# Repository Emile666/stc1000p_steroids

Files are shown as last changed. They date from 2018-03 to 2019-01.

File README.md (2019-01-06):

STC-1000p on steroids
==========

This is a version of the STC-1000p (STC-1000p-STM8) with new hardware and a new microcontroller, the **STM8S105C6T6**. It is a major upgrade to the stock **STM8S003F3** µC. In the version, you get all the exciting features from
the stc-1000p-stm8 version (including the PID-control with SSR output), PLUS:
- Three additional LEDs placed directly above the 7-segment display. These can be used for all kinds of indications.
- One-wire interface, so you can hook up a **DS18B20** One-Wire temperature-sensor for reliable temperature measurements.
- **I<sup>2</sup>C**-interface for additional connection to other hardware (e.g. a MCP23017 16-bit IO expander to control solenoid ball valves).
- An **UART** interface so that commands can be sent using serial communication.
- A **433 MHz** transmitter interface is added so that temperatures and relay on/off are sent (using the Fine Offset protocol from Matts original fimware).
- Interface for an **nRF24L01+** 2.4 GHz transceiver. Now you can control and communicate wireless with the STC1000p. The nRF24L01+ is known to have a large range (up to 100 metres is reported).

The **STM8S105C6T6** µC has 32 Kbytes of Flash memory, 1024 bytes of EEPROM and 2 Kbytes of RAM. So there's plenty of room for all new functionality. It also has more than sufficient IO pins, since it is a LQFP48 package.

I designed a new frontpanel PCB and backplane PCB that are the exact same sizes as the current PCBs. So it fits the existing housing.

Software Development Environment
-----------
- Cosmic STM8 compiler. A license can be obtained free of charge from Cosmic-software.com. Install this first.
- ST Visual Develop (STVD). This can be obtained free of charge from st.com
- A coloured ST-Link V2 USB adapter (which are very cheap to find on ebay)

In order to program this thing, you can't have a code-size limit of 8 Kbytes, so IAR will not do the job. Fortunately, the Cosmic STM8 development environment (IdeaSTM8) has been made available free-of-charge. Just register and download and you have 
a development environment that nicely supports this device.

Quick start
-----------
Assuming that you have bought (at least) one of those existing stc1000 on ebay/aliexpress, you need to do the following:
- Open the housing of the stc1000. There are a few clips on the side and you should make a cut in the sticker. Bend the clips (carefully) and pull the frontpanel out.
- The frontpanel PCB needs to be deconnected from the backplane. Remove all the solder-joints with the solder wick (or use a desoldering-iron). Place the solder wick over the solder-joints, heat it up with the soldering iron and make sure that the solder wick absorbs all solder.
After having done this, it is possible to remove the frontpanel from the backplane with just a little bit of pulling. Be careful, since you don't want to break anything.
- The 7-segment display is connected to the frontpanel with 12 pins and is going to be re-used. It is an essential part, so de-solder this from the frontpanel PCB. Be careful not to break anything.
- If you wish, you can desolder a few parts from the backplane PCB, such as terminal blocks and relays. I replaced the stock relays with 16 A versions (Omron G5LE-1-E 12VDC).
- Get yourself some PCBs (see below) and do some soldering...

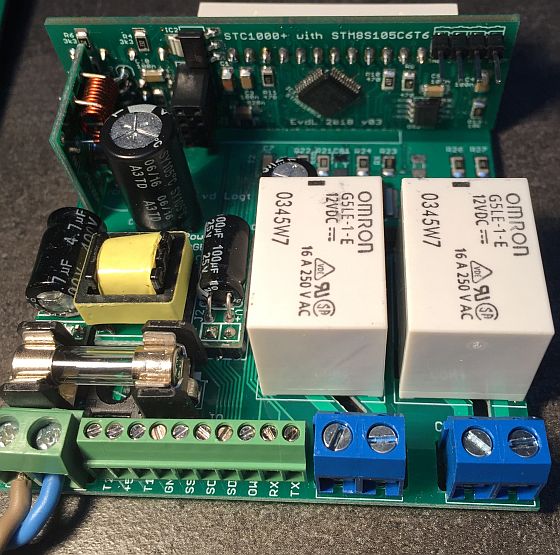
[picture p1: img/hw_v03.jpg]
hw_v03
<br>
*This is how it should look: frontpanel v03 connected to new backplane PCB*

Introduction
--------------
Much of this project is still work in progress, with hardware already pretty stable. The basic software from the stc1000p project runs, but most additional features mentioned above need to be added to the firmware.

I work on this from time to time, so it is not a completely finished project yet.

UART Communication protocol
--------------
If you connect an UART (+3.3V!) to USB device, it is possible to communicate with the stc1000 using commands. Currently the following commands are available:
- **S0**: print the current revision number of the software
- **S1**: Lists the address of all connected I2C devices. It should show at least 0x40, which is the I2C address for the DS2482 I2C to One-Wire device.
- **S2**: Lists all tasks of the scheduler. It should show 4 tasks.
- **S3**: Shows the temperature and status of a connected DS18B20 One-Wire device. It should read ds18b20_read():0 (1 = error) and the actual temperature of the sensor
- **O1** and **O0**: the O1 commands selects the One-wire temperature sensor over the default NTC sensor. The O0 command selects the default NTC sensor again. The selected sensorvalue is displayed on-screen and is used for both temperature and pid-control.

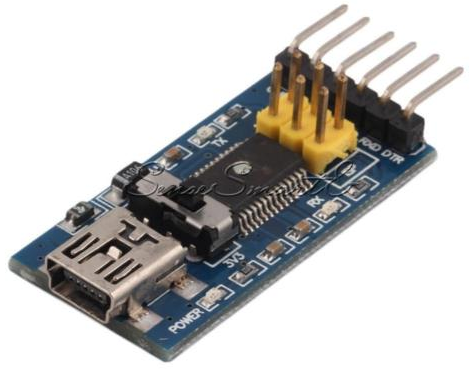
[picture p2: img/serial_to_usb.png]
serial_to_usb
<br>
*Serial (UART) to USB interface*

Frontpanel PCB
----------
Here's version 03 of the new frontpanel PCB.

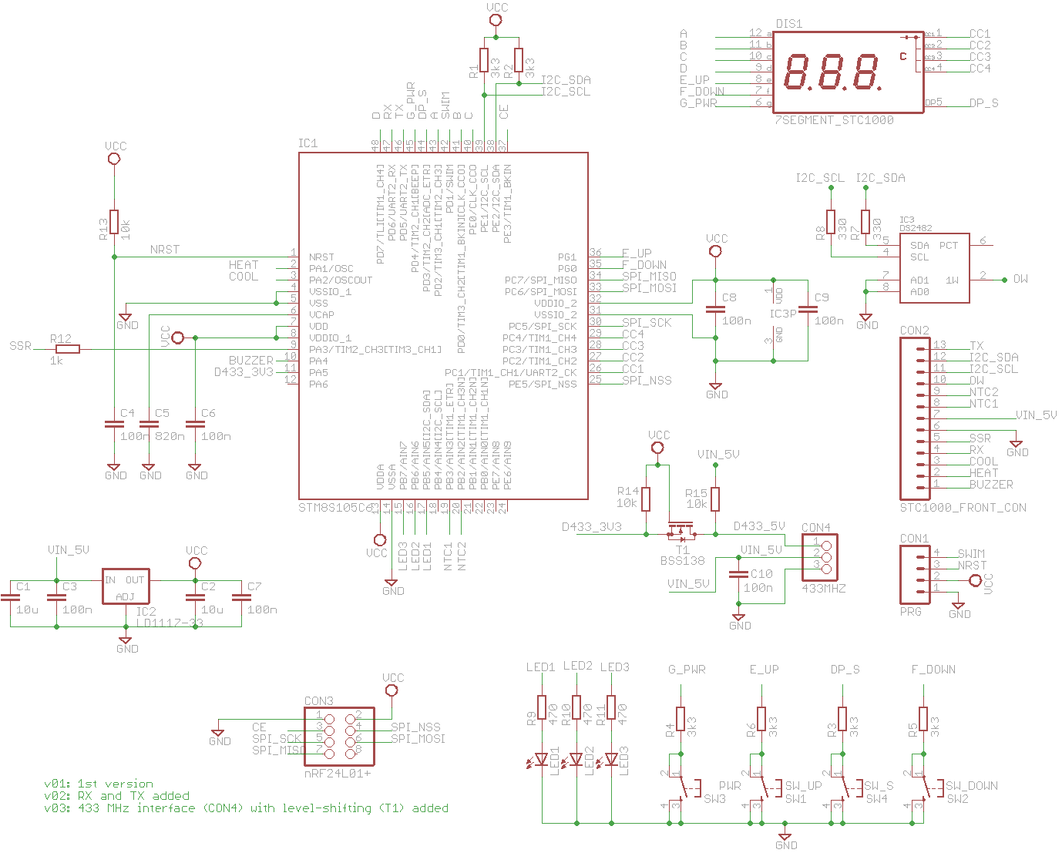
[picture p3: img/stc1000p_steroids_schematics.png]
<br>
*Eagle schematics v03 of the Frontpanel with an STM8S105C6 µC*

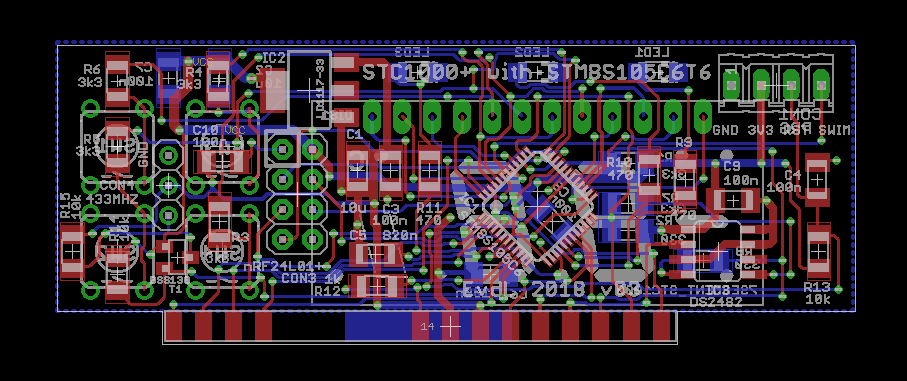
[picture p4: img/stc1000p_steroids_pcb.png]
<br>
*Eagle PCB of the Frontpanel, v03*

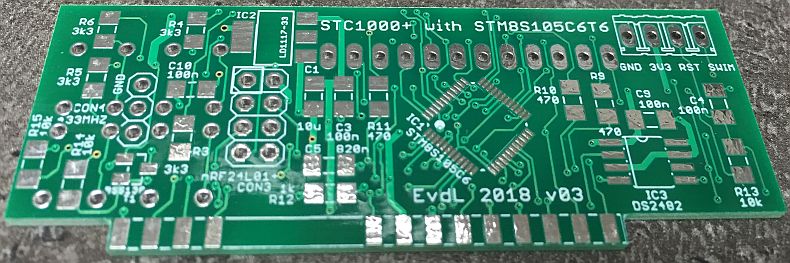
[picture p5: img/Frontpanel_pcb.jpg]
frontpanel
<br>
*PCB as received from the PCB manufacturer (allpcb.com).*

Backplane PCB
----------
Although it is possible to connect the frontpanel PCB directly to an existing backplane, it is much more useful to replace this with a new backplane. Main advantage is that you will have decent access to all new features via connectors at the back.

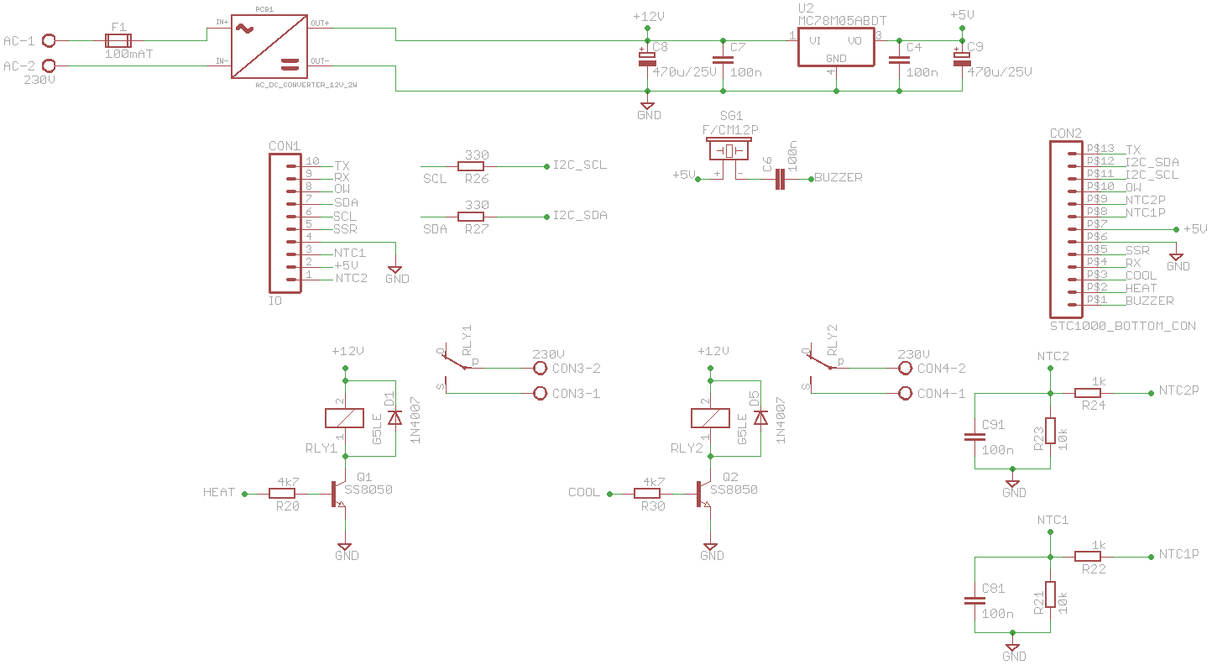
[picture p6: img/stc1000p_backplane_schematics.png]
backplane
<br>
*Eagle schematics of the new backplane*

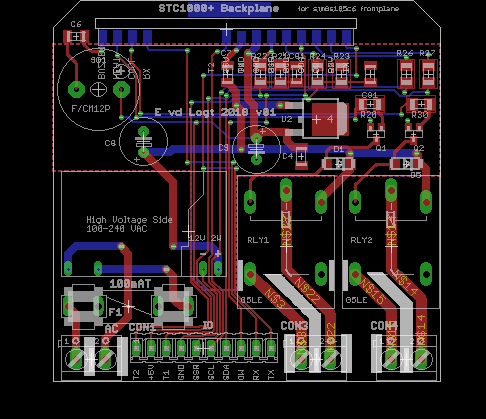
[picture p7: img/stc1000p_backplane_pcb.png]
backplane
<br>
*Eagle PCB of the new backplane*

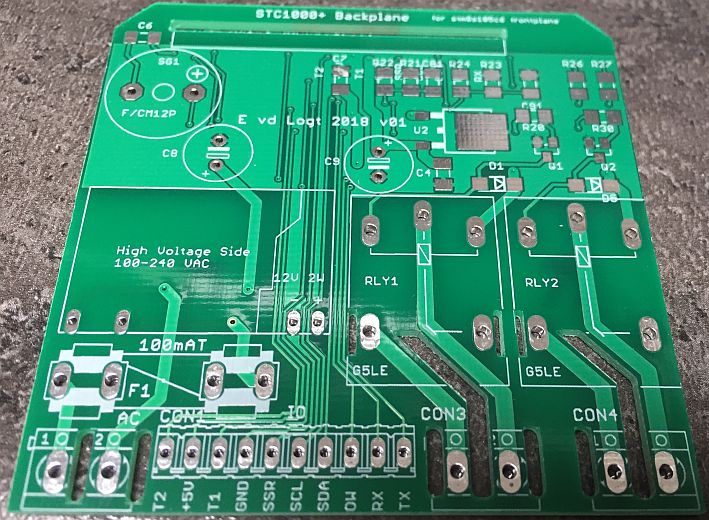
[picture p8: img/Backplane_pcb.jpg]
backplane
<br>
*PCB as received from the PCB manufacturer (allpcb.com).*

There's now a 10 pole terminal-block with the following connections:
- **T2**: connect a 2nd temperature sensor to this pin and the +3.3V pin (same as in Matts' firmware)
- **+5V**: +5V power-supply voltage (same as in original STC1000). **BUG**: this should be 3.3V.
- **T1**: connect a temperature sensor (10 k NTC) to this pin and the +5V pin (same as in original STC1000)
- **GND**: ground (0 V) connection. 
- **SSR**: SSR output. Connect this to the input line of a solid-state relay. This is a PID controlled output.
- **SCL**: Serial clock-line of the I<sup>2</sup>C interface.
- **SDA**: Serial data-line of the I<sup>2</sup>C interface.
- **OW**: One-wire output. Support a DS18B20 temperature sensor for more accurate readings.
- **RX**: Receive-data pin for the serial communication (UART). This is a 3.3 Volt pin, so do not connect higher voltages!
- **TX**: Transmit-data pin for the serial communication (UART). This is a 3.3 Volt pin, so do not connect higher voltages!

Updates
-------

|Date|Release|Description|
|----|---|---|
|2016-12-10|v1.00|First release |
|2018-03-23|v1.10|Frontpanel PCB update + new backplane PCB added|
|2019-01-07|v1.10|First working version with UART, One-Wire and Fine-Offset Protocol (433 MHz) added|

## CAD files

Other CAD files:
src/stc1000p_steroids.stp

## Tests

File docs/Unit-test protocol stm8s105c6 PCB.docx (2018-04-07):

Unit-test protocol stc1000 with stm8s105c6t6

Test-date:
PCB hardware version: | Frontpanel v03
Endresult Test | OK / NOK

Use this test protocol to test all microcontroller connections before mounting other components. Use a PCB microscope and a multimeter to test all connections.

CON1: 1 2 3 4

1 2

3 4

5 6

7 8

CON3

DIS: 12 11 10 9 8 7 6 5 4 3 2 1

HDR: 1 2 3 4 5 6 7 8 9 10 11 12 13

Figure 1: PCB Layout, topview

Number | μC pin | Connected with: | Name | Check?
1 | 01: NRST | CON1 pin 3 | NRST
2 | 02: PA1 | HDR pin 2 | HEAT
3 | 03: PA2 | HDR pin 3 | COOL
4 5 | 04: VSSIO_1 05: VSS | HDR pin 6 | GND
6 | 06: VCAP | C5 right | -
7 8 | 07: VDD 08: VDDIO_1 | CON1 pin 2 | VCC
9 | 09: PA3 | R12 right | -
10 | 10: PA4 | HDR pin 1 | BUZZER
11 | 11:PA5 | R14 bottom | D433_3V3
12 | 12:PA6 | - (NC) | -

Table 1: μC bottom-left pins

Number | μC pin | Connected with: | Name | Check?
1 | 13: VDD | CON1 pin 2 | VCC
2 | 14: VSS | HDR pin 6 | GND
3 | 15: PB7 | R11 bottom | LED3
4 | 16: PB6 | R10 bottom | LED2
5 | 17: PB5 | R9 bottom | LED1
6 9 10 11 12 | 18: PB4 21: PB1 22: PB0 23: PE7 24: PE6 | - (NC) | -
7 | 19: PB3 | HDR pin 8 | NTC1
8 | 20: PB2 | HDR pin 9 | NTC2

Table 2: μC bottom-right pins

Number | μC pin | Connected with: | Name | Check?
1 | 25: PE5 | CON3 pin 4 | SPI_NSS
2 | 26: PC1 | DIS pin 1 | CC1
3 | 27: PC2 | DIS pin 2 | CC2
4 | 28: PC3 | DIS pin 3 | CC3
5 | 29: PC4 | DIS pin 4 | CC4
6 | 30: PC5 | CON3 pin 5 | SPI_SCK
7 | 31: VSSIO_2 | HDR pin 6 | GND
8 | 32: VDDIO_2 | CON1 pin 2 | VCC
9 | 33: PC6 | CON3 pin 6 | SPI_MOSI
10 | 34: PC7 | CON3 pin 7 | SPI_MISO
11 | 35: PG0 | DIS pin 7 | F_DOWN
12 | 36: PG1 | DIS pin 8 | E_UP

Table 3: μC top-right pins

Number | μC pin | Connected with: | Name | Check?
1 | 25: PE3 | CON3 pin 3 | CE
2 | 26: PE2 | HDR pin 12 | I2C_SDA
3 | 27: PE1 | HDR pin 11 | I2C_SCL
4 | 28: PE0 | DIS pin 10 | C
5 | 29: PD0 | DIS pin 11 | B
6 | 30: PD1 | CON1 pin 4 | SWIM
7 | 31: PD2 | DIS pin 12 | A
8 | 32: PD3 | DIS pin 5 | DP_S
9 | 33: PD4 | DIS pin 6 | G_PWR
10 | 34: PD5 | HDR pin 13 | TX
11 | 35: PD6 | HDR pin 4 | RX
12 | 36: PD7 | DIS pin 9 | D

Table 4: μC top-left pins

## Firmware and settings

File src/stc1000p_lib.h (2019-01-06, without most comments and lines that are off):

#define STC1000P_LIB_H
#include "stdint.h"
#include <stdbool.h>
#include "stc1000p.h"
#include "eep.h"
#include "pid.h"
#define TEMP_MAX_F	      (2500)
#define TEMP_MIN_F	      (-400)
#define TEMP_CORR_MAX_F	  ( 100)
#define TEMP_CORR_MIN_F	  (-100)
#define TEMP_HYST_1_MAX_F ( 100)
#define TEMP_HYST_2_MAX_F ( 500)
#define SP_ALARM_MIN_F	  (-800)
#define SP_ALARM_MAX_F	  ( 800)
#define TEMP_MAX_C	      (1400)
#define TEMP_MIN_C	      (-400)
#define TEMP_CORR_MAX_C	  (  50)
#define TEMP_CORR_MIN_C	  ( -50)
#define TEMP_HYST_1_MAX_C (  50)
#define TEMP_HYST_2_MAX_C ( 250)
#define SP_ALARM_MIN_C	  (-400)
#define SP_ALARM_MAX_C	  ( 400)
#define DEFAULT_SP	      (200)
#define DEFAULT_hy	       (50)
#define DEFAULT_hy2	      (100)
#define NO_OF_PROFILES	 (6)
#define NO_OF_TT_PAIRS   (9)
#define PROFILE_SIZE     (2*(NO_OF_TT_PAIRS)+1)
#define MENU_ITEM_NO	 NO_OF_PROFILES
#define THERMOSTAT_MODE  NO_OF_PROFILES
enum e_item_type
{
    t_temperature = 0,
    t_tempdiff,
    t_hyst_1,
    t_hyst_2,
    t_sp_alarm,
    t_step,
    t_delay,
    t_runmode,
    t_duration,
    t_boolean,
    t_parameter
}; // e_item_type
#define MENU_TYPE_IS_TEMPERATURE(x) 	((x) <= t_sp_alarm)
#define MENU_DATA(_) \
	_(SP, 	LED_S, 	LED_P, 	LED_OFF, t_temperature,	DEFAULT_SP)	\
	_(hy, 	LED_h, 	LED_y, 	LED_OFF, t_hyst_1,	    DEFAULT_hy) 	\
	_(hy2, 	LED_h, 	LED_y, 	LED_2, 	 t_hyst_2, 	    DEFAULT_hy2)	\
	_(tc, 	LED_t, 	LED_c, 	LED_OFF, t_tempdiff,	3)		\
	_(tc2, 	LED_t, 	LED_c, 	LED_2, 	 t_tempdiff,	-2)		\
	_(SA, 	LED_S, 	LED_A, 	LED_OFF, t_sp_alarm,	0)		\
	_(St, 	LED_S, 	LED_t, 	LED_OFF, t_step,	    0)		\
	_(dh, 	LED_d, 	LED_h, 	LED_OFF, t_duration,	0)		\
	_(cd, 	LED_c, 	LED_d, 	LED_OFF, t_delay,	    5)		\
	_(hd, 	LED_h, 	LED_d, 	LED_OFF, t_delay,	    2)		\
	_(rP, 	LED_r, 	LED_P, 	LED_OFF, t_boolean,	    1)		\
	_(CF, 	LED_C, 	LED_F, 	LED_OFF, t_boolean,	    0)		\
	_(Pb2, 	LED_P, 	LED_b, 	LED_2, 	 t_boolean,	    0)		\
	_(HrS, 	LED_H, 	LED_r, 	LED_S, 	 t_boolean,	    1)		\
	_(Hc, 	LED_H, 	LED_c, 	LED_OFF, t_parameter,	80)		\
	_(Ti, 	LED_t, 	LED_I, 	LED_OFF, t_parameter,  280)		\
	_(Td, 	LED_t, 	LED_d, 	LED_OFF, t_parameter,   20)		\
	_(Ts, 	LED_t, 	LED_S, 	LED_OFF, t_parameter,    0)		\
	_(dI, 	LED_d, 	LED_I, 	LED_OFF, t_parameter,    0)		\
	_(One, 	LED_O, 	LED_n, 	LED_e,   t_parameter,    0)		\
	_(rn, 	LED_r, 	LED_n, 	LED_OFF, t_runmode,    NO_OF_PROFILES)
#define ENUM_VALUES(name,led10ch,led1ch,led01ch,type,default_value) name,
#define EEPROM_DEFAULTS(name,led10ch,led1ch,led01ch,type,default_value) default_value,
enum menu_enum
{
    MENU_DATA(ENUM_VALUES) _last_
}; // menu_enum
#define EEADR_PROFILE_SETPOINT(profile, step)	(((profile)*PROFILE_SIZE) + ((step)<<1))
#define EEADR_PROFILE_DURATION(profile, step)	EEADR_PROFILE_SETPOINT(profile, step) + 1
#define EEADR_MENU				                EEADR_PROFILE_SETPOINT(NO_OF_PROFILES, 0)
#define EEADR_MENU_ITEM(name)		            (EEADR_MENU + (name))
#define MI_CI_TO_EEADR(mi, ci)	                ((mi)*PROFILE_SIZE + (ci))
#define EEADR_POWER_ON				            (EEADR_MENU_ITEM(rn) + 1)
#define BTN_PWR	 (0x88)
#define BTN_S    (0x44)
#define BTN_UP	 (0x22)
#define BTN_DOWN (0x11)
#define BTN_IDLE(btn)		  ((_buttons & (btn)) == 0x00)
#define BTN_PRESSED(btn)	  ((_buttons & (btn)) == ((btn) & 0x0f))
#define BTN_HELD(btn)		  ((_buttons & (btn)) == (btn))
#define BTN_RELEASED(btn)	  ((_buttons & (btn)) == ((btn) & 0xf0))
#define BTN_HELD_OR_RELEASED(btn) ((_buttons & (btn) & 0xf0))
#define LEDS_RUN_MODE (0)
#define LEDS_MENU     (1)
#define LEDS_INT      (0)
#define LEDS_TEMP     (1)
#define TMR_POWERDOWN          (30)
#define TMR_SHOW_PROFILE_ITEM  (15)
#define TMR_NO_KEY_TIMEOUT    (150)
#define TMR_KEY_ACC            (20)
struct s_menu
{
   uint8_t led_c_10;
   uint8_t led_c_1;
   uint8_t led_c_01;
   uint8_t type;
}; // s_menu
#define TO_STRUCT(name, led10ch, led1ch, led01ch, type, default_value) \
        { led10ch, led1ch, led01ch, type },
enum menu_states
{
    MENU_IDLE = 0,            // Default menu
    MENU_SHOW_VERSION,        // Show version number of firmware
    MENU_SHOW_STATE_UP,       // Show Setpoint value
    MENU_SHOW_STATE_DOWN,     // Show profile number or th
    MENU_SHOW_STATE_DOWN_2,   // Show current step number within profile
    MENU_SHOW_STATE_DOWN_3,   // Show current duration of profile
    MENU_POWER_DOWN_WAIT,     // Power-down mode, display is off
    MENU_SHOW_MENU_ITEM,      // Show name of menu-item / profile
    MENU_SET_MENU_ITEM,       // Navigate through menu-items / profile
    MENU_SHOW_CONFIG_ITEM,    // Show name of menu-item / profile-item
    MENU_SET_CONFIG_ITEM,     // Change menu-item / profile-item
    MENU_SHOW_CONFIG_VALUE,   // Show value of menu-item / profile-item
    MENU_SET_CONFIG_VALUE     // Change value of menu-item / profile-item
}; // menu_states
uint16_t divu10(uint16_t n);
void     prx_to_led(uint8_t run_mode, uint8_t is_menu);
void     value_to_led(int value, uint8_t decimal);
void     update_profile(void);
int16_t  range(int16_t x, int16_t min, int16_t max);
int16_t  check_config_value(int16_t config_value, uint8_t eeadr);
void     read_buttons(void);
void     menu_fsm(void);
void     temperature_control(int16_t temp);
void     pid_control(int16_t temp);

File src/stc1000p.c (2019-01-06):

/*==================================================================
  File Name    : stc1000p.c
  Author       : Emile
  ------------------------------------------------------------------
  Purpose : This files contains the main() function and all the 
            hardware related functions for the STM8S105C6T6 uC.
            It is meant for the STC1000 with newly developed HW.
  ------------------------------------------------------------------
  STC1000+ is free software: you can redistribute it and/or modify
  it under the terms of the GNU General Public License as published by
  the Free Software Foundation, either version 3 of the License, or
  (at your option) any later version.
 
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
  You should have received a copy of the GNU General Public License
  along with STC1000+.  If not, see <http://www.gnu.org/licenses/>.
  ------------------------------------------------------------------
  $Log: $
  ==================================================================
*/ 
#include "stc1000p.h"
#include "stc1000p_lib.h"
#include "scheduler.h"
#include "adc.h"
#include "eep.h"
#include "i2c.h"
#include "one_wire.h"
#include "nrf24.h"
#include "fo433.h"
#include "comms.h"

// Global variables
uint8_t   ad_err1 = false; // used for adc range checking
uint8_t   ad_err2 = false; // used for adc range checking
bool      probe2  = false; // cached flag indicating whether 2nd probe is active
bool      show_sa_alarm = false;
bool      ad_ch   = false; // used in adc_task()
uint16_t  ad_ntc1 = (512L << FILTER_SHIFT);
uint16_t  ad_ntc2 = (512L << FILTER_SHIFT);
int16_t   temp_ntc1;         // The temperature in E-1 °C from NTC probe 1
int16_t   temp_ntc2;         // The temperature in E-1 °C from NTC probe 2
uint8_t   mpx_nr = 0;        // Used in multiplexer() function
int16_t   pwr_on_tmr = 1000; // Needed for 7-segment display test
int16_t   temp1_ow_10;       // Temperature from DS18B20 in °C * 10
uint8_t   temp1_ow_err = 0;  // 1 = Read error from DS18B20
uint8_t   use_one_wire = 0;  // 1 = Use one-wire sensor instead of NTC probe 1
bool      msec051 = false;   // millisecond indicator

// Radio pipe addresses for the communication nodes
//@near uint8_t tx_address[5] = {0xFF,0xFF,0xFF,0xFF,0xFF};
//@near uint8_t rx_address[5] = {0xFF,0xFF,0xFF,0xFF,0xFF};

// External variables, defined in other files
extern uint8_t  led_e;                 // value of extra LEDs
extern uint8_t  led_10, led_1, led_01; // values of 10s, 1s and 0.1s
extern bool     pwr_on;           // True = power ON, False = power OFF
extern uint8_t  sensor2_selected; // DOWN button pressed < 3 sec. shows 2nd temperature / pid_output
extern bool     minutes;          // timing control: false = hours, true = minutes
extern bool     menu_is_idle;     // No menus in STD active
extern bool     fahrenheit;       // false = Celsius, true = Fahrenheit
extern uint16_t cooling_delay;    // Initial cooling delay
extern uint16_t heating_delay;    // Initial heating delay
extern int16_t  setpoint;         // local copy of SP variable
extern uint8_t  ts;               // Parameter value for sample time [sec.]
extern int16_t  pid_out;          // Output from PID controller in E-1 %
extern int16_t  @eeprom eedata[]; // Link to .eeprom section
extern uint32_t t2_millis;        // needed for delay_msec()
extern uint8_t  rs232_inbuf[];

/*-----------------------------------------------------------------------------
  Purpose  : This routine multiplexes the 4 segments of the 7-segment displays.
             It runs at 2 kHz, so there's a full update after every 2 msec.
  Variables: -
  Returns  : -
  ---------------------------------------------------------------------------*/
void multiplexer(void)
{
    // Disable all 7-segment LEDs and common-cathode pins
    // PD7 PG1 PG0 PD4 PD3 PD2 PE0 PD0
    //  D   E   F   G   dp  A   C   B 
    PG_ODR    &= ~PG_SEG7; // Clear LEDs
    PD_ODR    &= ~PD_SEG7; // Clear LEDs
    PE_ODR    &= ~PE_SEG7; // Clear LEDs
    PC_ODR    |=  CC_ALL;  // Disable common-cathodes
    
    switch (mpx_nr)
    {
        case 0: // output 10s digit
            PG_ODR |= ((led_10 >> 5) & PG_SEG7); // Update 7-segment E+F
            PD_ODR |= (led_10 & PD_SEG7);        // Update 7-segments
            PE_ODR |= ((led_10 >> 1) & PE_SEG7); // Update 7-segment C
            PC_ODR &= ~CC_10;    // Enable  common-cathode for 10s
            mpx_nr = 1;
            break;
        case 1: // output 1s digit
            PG_ODR |= ((led_1 >> 5) & PG_SEG7); // Update 7-segment E+F
            PD_ODR |= (led_1 & PD_SEG7);        // Update 7-segments
            PE_ODR |= ((led_1 >> 1) & PE_SEG7); // Update 7-segment C
            PC_ODR &= ~CC_1;     // Enable  common-cathode for 1s
            mpx_nr = 2;
            break;
        case 2: // output 01s digit
            PG_ODR |= ((led_01 >> 5) & PG_SEG7); // Update 7-segment E+F
            PD_ODR |= (led_01 & PD_SEG7);        // Update 7-segments
            PE_ODR |= ((led_01 >> 1) & PE_SEG7); // Update 7-segment C
            PC_ODR &= ~CC_01;    // Enable common-cathode for 0.1s
            mpx_nr = 3;
            break;
        case 3: // outputs special digits
            PG_ODR |= ((led_e >> 5) & PG_SEG7); // Update 7-segment E+F
            PD_ODR |= (led_e & PD_SEG7);        // Update 7-segments
            PE_ODR |= ((led_e >> 1) & PE_SEG7); // Update 7-segment C
            PC_ODR &= ~CC_e;     // Enable common-cathode for extras
        default: // FALL-THROUGH (less code-size)
            mpx_nr = 0;
            break;
            //mpx_nr = 0;
            //break;
    } // switch            
} // multiplexer()

/*-----------------------------------------------------------------------------
  Purpose  : This is the interrupt routine for the Timer 2 Overflow handler.
             It runs at 2 kHz and drives the scheduler and the multiplexer.
             Measured timing: 1.8 usec and 26 usec duration (5.2 %).
  Variables: -
  Returns  : -
  ---------------------------------------------------------------------------*/
@interrupt void TIM2_UPD_OVF_IRQHandler(void)
{
    PA_ODR |= ISR_OUT; // Time-measurement interrupt routine
    fo433_isr();         // This should run at 2 kHz
    msec051 = !msec051;  // msec indicator
    if (msec051)
    {   // this runs every millisecond
        t2_millis++;       // update millisecond counter
        scheduler_isr();   // Run scheduler interrupt function
    
        if (!pwr_on)
        {   // Display OFF on dispay
            led_10     = LED_O;
            led_1      = led_01 = LED_F;
            led_e      = LED_OFF;
            pwr_on_tmr = 1000; // 1 second
        } // if
        else if (pwr_on_tmr > 0)
        {	// 7-segment display test for 1 second
            pwr_on_tmr--;
            led_10 = led_1 = led_01 = led_e = LED_ON;
        } // else if
        multiplexer();           // Run multiplexer for Display
    } // if
    PA_ODR   &= ~ISR_OUT;      // Time-measurement interrupt routine
    TIM2_SR1 &= ~TIM2_SR1_UIF; // Reset interrupt (UIF bit) so it will not fire again straight away.
} // TIM2_UPD_OVF_IRQHandler()

/*-----------------------------------------------------------------------------
  Purpose  : This routine initialises the system clock to run at 16 MHz.
             It uses the internal HSI oscillator.
  Variables: -
  Returns  : -
  ---------------------------------------------------------------------------*/
void initialise_system_clock(void)
{
    CLK_ICKCR  = 0;                //  Reset the Internal Clock Register.
    CLK_ICKCR |= CLK_ICKCR_HSIEN;  //  Enable the HSI.
    while ((CLK_ICKCR & CLK_ICKCR_HSIRDY) == 0); //  Wait for the HSI to be ready for use.
    CLK_CKDIVR     = 0;            //  Ensure the clocks are running at full speed.
 
    // The datasheet lists that the max. ADC clock is equal to 6 MHz (4 MHz when on 3.3V).
    // Because fMASTER is now at 16 MHz, we need to set the ADC-prescaler to 4.
    ADC_CR1     &= ~ADC_CR1_SPSEL_MSK;
    ADC_CR1     |= 0x20;          //  Set prescaler (SPSEL bits) to 4, fADC = 4 MHz
    CLK_SWIMCCR  = 0x00;          //  Set SWIM to run at clock / 2.
    CLK_SWR      = 0xE1;          //  Use HSI as the clock source.
    CLK_SWCR     = 0x00;          //  Reset the clock switch control register.
    CLK_SWCR    |= CLK_SWCR_SWEN; //  Enable switching.
    while ((CLK_SWCR & CLK_SWCR_SWBSY) != 0);  //  Pause while the clock switch is busy.
} // initialise_system_clock()

/*-----------------------------------------------------------------------------
  Purpose  : This routine initialises Timer 2 to generate a 2 kHz interrupt.
             16 MHz / (16 * 500) = 2000 Hz (500 = 0x01F4)
  Variables: -
  Returns  : -
  ---------------------------------------------------------------------------*/
void setup_timer2(void)
{
    TIM2_PSCR = 0x04;         //  Prescaler = 16
    TIM2_ARRH = 0x01;         //  High byte of 500
    TIM2_ARRL = 0xF4;         //  Low  byte of 500
    TIM2_IER  = TIM2_IER_UIE; //  Enable the update interrupts, disable all others
    TIM2_CR1  = TIM2_CR1_CEN; //  Finally enable the timer
} // setup_timer2()

/*-----------------------------------------------------------------------------
  Purpose  : This routine initialises all the GPIO pins of the STM8 uC.
             See stc1000p.h for a detailed description of all pin-functions.
  Variables: -
  Returns  : -
  ---------------------------------------------------------------------------*/
void setup_gpio_ports(void)
{
	PA_DDR     |=  (SSR | COOL | HEAT | ALARM | D433_OUT | ISR_OUT); // Set as output
	PA_DDR     &= ~PA_NC;                      // Set unused ports as input
	PA_CR1     |=  PA_NC;                      // Enable pull-up
    PA_CR1     |=  (SSR | COOL | HEAT | ALARM | D433_OUT | ISR_OUT); // Set to Push-Pull
    PA_ODR     &= ~(SSR | COOL | HEAT | ALARM | D433_OUT | ISR_OUT); // Disable PORTA outputs
		
    PB_DDR     |= (LED1 | LED2 | LED3);  // Set as output
    PB_DDR     &= ~(PB_NC | AD_CHANNELS);            // Set as input
    PB_CR1     |= PB_NC;                             // Enable pull-up
	PB_CR1     &= ~AD_CHANNELS; // Set to floating-inputs (required by ADC)
	PB_CR1     |=  (LED1 | LED2 | LED3); // Set to Push-Pull
    PB_ODR     &= ~(LED1 | LED2 | LED3); // Disable PORTB outputs
		
    PC_DDR     |=  (SPI_MOSI | SPI_CLK | CC_ALL); // Set as outputs
	PC_CR1     |=  (SPI_MOSI | SPI_CLK | CC_ALL); // Set to Push-Pull
	PC_CR2     |=  (SPI_MOSI | SPI_CLK);          // Set to 10 MHz
    PC_ODR     &= ~(SPI_MOSI | SPI_CLK);          // Disable PORTC outputs
    PC_ODR     |=  CC_ALL;                        // Disable Common-Cathodes
    PC_DDR     &= ~SPI_MISO;                      // set as Input
	PC_CR1     &= ~SPI_MISO;                      // set to Floating
		
    PD_DDR     |=  PD_SEG7;          // Set 7-segment/key pins as output
    PD_CR1     |=  PD_SEG7;          // Set 7-segment/key pins to Push-Pull
    PD_ODR     &= ~PD_SEG7;          // Turn off all 7-segment/key pins

    PE_ODR     |=  (I2C_SCL | I2C_SDA); // Must be set here, or I2C will not work
    PE_DDR     |=  (SPI_NSS | NRF24_CE | PE_SEG7 | I2C_SCL | I2C_SDA); // Set as outputs
	PE_DDR     &= ~PE_NC;               // Set unused ports as input
	PE_CR1     |=  PE_NC;               // Enable pull-ups
    PE_CR1     |=  (SPI_NSS | NRF24_CE | PE_SEG7);    // Set to Push-Pull
	//PE_CR2     |=  (I2C_SCL | I2C_SDA); // Set speed to 10 MHz
    PE_ODR     &= ~PE_SEG7;             // Turn off 7-segment C
    PE_ODR     |=  (SPI_NSS);           // Turn off SPI_NSS
    PE_ODR     &= ~NRF24_CE;            // Set NRF24_CE low
    
    PG_DDR     |=  PG_SEG7;      // Set 7-segment/key pins as output
    PG_CR1     |=  PG_SEG7;      // Set 7-segment/key pins to Push-Pull
    PG_ODR     &= ~PG_SEG7;      // Turn off all 7-segment/key pins
} // setup_output_ports()

/*-----------------------------------------------------------------------------
  Purpose  : This task is called every 500 msec. and processes the NTC 
             temperature probes from NTC1 (PB3/AIN3) and NTC2 (PB2/AIN2)
  Variables: -
  Returns  : -
  ---------------------------------------------------------------------------*/
void adc_task(void)
{
  uint16_t temp;
  uint8_t  i;
  
  // Save registers that interferes with LED's and disable common-cathodes
  disable_interrupts();       // Disable interrups while reading buttons
  for (i = 0; i < 200; i++) ; // Disable to let input signal settle
  if (ad_ch)
  {  // Process NTC probe 1
     temp       = read_adc(AD_NTC1);
     ad_ntc1    = ((ad_ntc1 - (ad_ntc1 >> FILTER_SHIFT)) + temp);
     temp_ntc1  = ad_to_temp(ad_ntc1,&ad_err1);
     temp_ntc1 += eeprom_read_config(EEADR_MENU_ITEM(tc));
  } // if
  else
  {  // Process NTC probe 2
     temp       = read_adc(AD_NTC2);
     ad_ntc2    = ((ad_ntc2 - (ad_ntc2 >> FILTER_SHIFT)) + temp);
     temp_ntc2  = ad_to_temp(ad_ntc2,&ad_err2);
     temp_ntc2 += eeprom_read_config(EEADR_MENU_ITEM(tc2));
  } // else
  ad_ch = !ad_ch;
  enable_interrupts();     // Re-enable Interrupts
} // adc_task()

/*-----------------------------------------------------------------------------
  Purpose  : This task is called every 100 msec. and creates a slow PWM signal
             from pid_output: T = 12.5 seconds. This signal can be used to
             drive a Solid-State Relay (SSR).
  Variables: pid_out (global) is used
  Returns  : -
  ---------------------------------------------------------------------------*/
void pid_to_time(void)
{
    static uint8_t std_ptt = 1; // state [on, off]
    static uint8_t ltmr    = 0; // #times to set S3 to 0
    static uint8_t htmr    = 0; // #times to set S3 to 1
    uint16_t x;                 // temp. variable
     
    x   = (pid_out < 0) ? -pid_out : pid_out;
    x >>= 3; // divide by 8 to give 1.25 * pid_out
    
    switch (std_ptt)
    {
        case 0: // OFF
            if (ltmr == 0)
            {   // End of low-time
                htmr = (uint8_t)x; // htmr = 1.25 * pid_out
                if ((htmr > 0) && pwr_on) std_ptt = 1;
            } // if
            else ltmr--; // decrease timer
            SSR_OFF;     // SSR output = 0
            break;
        case 1: // ON
            if (htmr == 0)
            {   // End of high-time
                ltmr = (uint8_t)(125 - x); // ltmr = 1.25 * (100 - pid_out)
                if ((ltmr > 0) || !pwr_on) std_ptt = 0;
            } // if
            else htmr--; // decrease timer
            SSR_ON;      // SSR output = 1
            break;
    } // switch
} // pid_to_time()

/*-----------------------------------------------------------------------------
  Purpose  : This task is called every 100 msec. and reads the buttons, runs
             the STD and updates the 7-segment display.
  Variables: -
  Returns  : -
  ---------------------------------------------------------------------------*/
void std_task(void)
{
    read_buttons(); // reads the buttons keys, result is stored in _buttons
    menu_fsm();     // Finite State Machine menu
    pid_to_time();  // Make Slow-PWM signal and send to SSR output-port
} // std_task()

/*-----------------------------------------------------------------------------
  Purpose  : This task is called every second and contains the main control
             task for the device. It also calls temperature_control() / 
             pid_ctrl() and is used to drive the 433 MHZ transmitter FSM.
  Variables: -
  Returns  : -
  ---------------------------------------------------------------------------*/
void ctrl_task(void)
{
   int16_t sa, diff, temp;
   
	  if (PB_IDR & LED2)    // Orange LED, Alive indicator
		   PB_ODR &= ~LED2;
	  else PB_ODR |=  LED2;
		
    if (eeprom_read_config(EEADR_MENU_ITEM(CF))) // true = Fahrenheit
         fahrenheit = true;
    else fahrenheit = false;
    if (eeprom_read_config(EEADR_MENU_ITEM(HrS))) // true = hours
         minutes = false; // control-timing is in hours 
    else minutes = true;  // control-timing is in minutes

   // Start with updating the alarm
   // cache whether the 2nd probe is enabled or not.
   if (eeprom_read_config(EEADR_MENU_ITEM(Pb2))) 
        probe2 = true;
   else probe2 = false;
   if (ad_err1 || (ad_err2 && probe2))
   {
       ALARM_ON;   // enable the piezo buzzer
       RELAYS_OFF; // disable the output relays
       if (menu_is_idle)
       {  // Make it less anoying to nagivate menu during alarm
          led_10 = LED_A;
	      led_1  = LED_L;
	      led_e  = led_01 = LED_OFF;
       } // if
       cooling_delay = heating_delay = 60;
   } else {
       ALARM_OFF; // reset the piezo buzzer
       if(((uint8_t)eeprom_read_config(EEADR_MENU_ITEM(rn))) < THERMOSTAT_MODE)
            led_e |=  LED_SET; // Indicate profile mode
       else led_e &= ~LED_SET;
 
       ts            = eeprom_read_config(EEADR_MENU_ITEM(Ts));  // Read Ts [seconds]
       sa            = eeprom_read_config(EEADR_MENU_ITEM(SA));  // Show Alarm parameter
       use_one_wire  = eeprom_read_config(EEADR_MENU_ITEM(One)); // 1 = use One-Wire sensor
       if (use_one_wire) temp = temp1_ow_10; // use one-wire sensor
       else              temp = temp_ntc1;   // use NTC1 temp. sensor
       
       if (sa)
       {
           if (minutes) // is timing-control in minutes?
                diff = temp - setpoint;
           else diff = temp - eeprom_read_config(EEADR_MENU_ITEM(SP));

           if (diff < 0) diff = -diff;
	       if (sa < 0)
           {
  	          sa = -sa;
              if (diff <= sa)
                   ALARM_ON;  // enable the piezo buzzer
              else ALARM_OFF; // reset the piezo buzzer
           } else {
              if (diff >= sa)
                   ALARM_ON;  // enable the piezo buzzer
              else ALARM_OFF; // reset the piezo buzzer
	       } // if
       } // if
       if (ts == 0)                   // PID Ts parameter is 0?
       {
           temperature_control(temp); // Run thermostat
           pid_out = 0;               // Disable PID-output
       } // if
       else pid_control(temp);        // Run PID controller
       if (menu_is_idle)              // show temperature if menu is idle
       {
           if ((ALARM_STATUS) && show_sa_alarm)
           {
               led_10 = LED_S;
               led_1  = LED_A;
	           led_01 = LED_OFF;
           } else {
               led_e &= ~LED_POINT; // LED in middle, does not seem to work
               switch (sensor2_selected)
               {
                   case 0: value_to_led(temp,LEDS_TEMP); 
                           break;
                   case 1: value_to_led(temp_ntc2,LEDS_TEMP); 
                           led_e |= LED_POINT;
                           break;
                   case 2: value_to_led(pid_out  ,LEDS_INT) ; 
                           break;
               } // switch
           } // else
           show_sa_alarm = !show_sa_alarm;
       } // if
   } // else
   fo433_fsm(temp); // call the FO433 state machine
   one_wire_task(); // read from one-wire temperature sensor if present
} // ctrl_task()

/*-----------------------------------------------------------------------------
  Purpose  : This task is called every minute or every hour and updates the
             current running temperature profile.
  Variables: minutes: timing control: false = hours, true = minutes
  Returns  : -
  ---------------------------------------------------------------------------*/
void prfl_task(void)
{
    static uint8_t min = 0;
    
    if (minutes)
    {   // call every minute
        update_profile();
        min = 0;
    } else {
        if (++min >= 60)
        {   // call every hour
            min = 0;
            update_profile(); 
        } // if
    } // else
} // prfl_task();
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
int main(void)
{
	char    s[30];      // Needed for xputs() and sprintf()
	int ee = eedata[0]; // This is to prevent the linker from removing .eeprom section
	uint8_t ok, bb = false;
	
    disable_interrupts();
    initialise_system_clock(); // Set system-clock to 16 MHz
    setup_gpio_ports();        // Init. needed output-ports for LED and keys
    setup_timer2();            // Set Timer 2 to 1 kHz
    pwr_on = eeprom_read_config(EEADR_POWER_ON); // check pwr_on flag
    i2c_init();                // Init. I2C bus
    uart_init();               // Init. serial communication
    
    // Initialise all tasks for the scheduler
	scheduler_init();                    // clear task_list struct
    add_task(adc_task ,"ADC",  0,  500); // every 500 msec.
    add_task(std_task ,"STD", 50,  100); // every 100 msec.
    add_task(ctrl_task,"CTL",200, 1000); // every second
    add_task(prfl_task,"PRF",300,60000); // every minute / hour
    //add_task(spi_task ,"SPI",400, 5000); // every 5 seconds
    //disable_task("SPI");                 // Enable it after init is done
    enable_interrupts();
    print_version_number();
    //nrf24_init();                 // Init. nRF24l01p module on SPI bus
    //nrf24_config(110,6);          // Channel #110 , payload length: 6
    //nrf24_tx_address(tx_address); // Set the device addresses
    //nrf24_rx_address(rx_address);        
    //enable_task("SPI");

    ok = ds2482_detect(DS2482_ADDR);   // true
    xputs("ds2482_detect:");
    if (ok) xputs("1\r\n");
    else    xputs("0\r\n");
    
    while (1)
    {   // background-processes
        dispatch_tasks();     // Run task-scheduler()
   		switch (rs232_command_handler()) // run command handler continuously
		{
			case ERR_CMD: xputs("Command Error\r\n"); break;
			case ERR_NUM: sprintf(s,"Number Error (%s)\r\n",rs232_inbuf);
						  xputs(s);  
						  break;
			default     : break;
		} // switch
        //wait_for_interrupt(); // do nothing
    } // while
} // main()

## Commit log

2016-12-10 First version, schematic and PCB added
2017-01-03 Picture of PCBs added.
2017-07-21 Update: Work in Progress
    [stc1000p_steroids.stp]
2018-03-23 Frontpanel PCB update + new backplane PCB
2018-04-06 Baseline for frontpanel PCB v03 + one-wire + FO433 protocol added
    One-wire functionality is added, but not tested yet. FO433 works fine.
    [stc1000p_steroids.stp]
2018-04-07 Unit-test added for PCB HW v03
2019-01-06 UART + comm. protocol added
    [stc1000p_steroids.stp]
